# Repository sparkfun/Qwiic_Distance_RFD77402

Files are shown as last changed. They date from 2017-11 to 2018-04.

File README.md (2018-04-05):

Qwiic Distance Sensor - RFD77402
========================================

SparkFun Distance Sensor - RFD77402

[*Distance Sensor-RFD77402 (SEN-14539)*](https://www.sparkfun.com/products/14539)

The Qwiic Distance Sensor uses the RFD77402 sensor utilizing VCSEL or vertical-cavity surface-emitting laser and a 3 pixel camera to measure the amount of time to a target. This gives you amazing millimeter prescision with low-cost and low power.

Documentation
--------------
* **[Library](https://github.com/sparkfun/SparkFun_RFD77402_Arduino_Library)** - Arduino library for the RFD77402 Breakout Board.
* **[Hookup Guide](https://learn.sparkfun.com/tutorials/qwiic-distance-sensor-rfd77402-hookup-guide)** - Basic hookup guide for the RFD77402 Breakout Board.
* **[Qwiic System](http://www.sparkfun.com/qwiic)** - The Qwiic system enables fast and solderless connection between popular platforms and various sensors and actuators.

Product Versions
----------------
* [SEN-14539](https://www.sparkfun.com/products/14539)
* [SPX-14343](https://www.sparkfun.com/products/14343)

License Information
-------------------

This product is _**open source**_!

Please review the LICENSE.md file for license information.

If you have any questions or concerns on licensing, please contact techsupport@sparkfun.com.

Distributed as-is; no warranty is given.

- Your friends at SparkFun.

_<COLLABORATION CREDIT>_

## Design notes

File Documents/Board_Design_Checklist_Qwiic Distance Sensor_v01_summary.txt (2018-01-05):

1) Are the part libraries consistent with eagle github repo? [YES]
comment: Kicad, but yes

2) Do all VCC connections use the VCC symbol (oriented upward)? [YES]
comment: 3.3v

3) Is the bottom left corner board dimensions at 0,0? [YES]
comment: frame at 0,0

4) Is the board dimension outline correct thickness? (0.008 inch) [NO]
comment: .0059 (leaving as is, kicad)

5) If it is a 3-way jumper, is there a label on each side of the jumper? [NO]
comment: i2c pu

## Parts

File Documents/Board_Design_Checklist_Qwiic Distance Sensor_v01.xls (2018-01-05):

SECTION | CHECK | STATUS | DEPENDANCY | CORRECT ANSWER | USER | USER-ANSWER | COMMENT | WIKI_LINK
Macro | is_revision | 1
Macro | has_pth | 0
Macro | has_i2c | 1
Macro | has_SPI | 0
Macro | has_1x6_ftdi_header | 0
Macro | has_jumpers | 1
Macro | has_leds | 0
Macro | has_vreg | 0
Macro | has_QFN | 0
Macro | has_SS | 0
Macro | has_multi_sheet | 0
Macro | is_kit | 0
Macro | has_serial | 0
Macro | is_4layer | 0
Macro | has_milling | 0
Macro | has_switchorbutton | 0
General | Are the part libraries consistent with eagle github repo? |  |  | YES | andrew.england | YES | Kicad, but yes
Schematic | Is the proper frame with CC attribution used? |  |  | YES | andrew.england | YES
Schematic | Are all schematic objects inside the frame? |  |  | YES | andrew.england | YES
Schematic | Is there a SparkFun Logo? |  |  | YES | andrew.england | YES
Schematic | Is there an OSHW logo? |  |  | YES | andrew.england | YES
Schematic | Is proper attribution given to the original designer? |  |  | YES | andrew.england | YES
Schematic | Is "Revised by: " and the reviser's name present? |  | 2 | YES | andrew.england | YES
Schematic | Are NET labels the correct FLAG type? |  |  | YES | andrew.england | YES
Schematic | Have all nets been drawn straight out from pin connections at least one grid space? |  |  | YES | andrew.england | YES
Schematic | Are all net lines 0.006 inch? |  |  | YES | andrew.england | YES
Schematic | Are there any 4-way junctions? |  |  | NO | andrew.england | NO
Schematic | Are junction dots used for all 3-wire connections? |  |  | YES | andrew.england | YES
Schematic | Are the fiducials in the lower right corner? |  |  | YES | andrew.england | YES
Schematic | Are the standoffs in the lower right corner? |  |  | YES | andrew.england | YES
Schematic | Are dashed grey lines ('info' eagle layer 97) used to clearly separate different areas? |  |  | YES | andrew.england | YES
Schematic | Is the version number correct? |  |  | YES | andrew.england | YES
Schematic | Is the version number included on all sheets? |  | 12 | YES | andrew.england | *n/a*
Schematic | Do all GND connections use the GND symbol (oriented downward)? |  |  | YES | andrew.england | YES
Schematic | Do all VCC connections use the VCC symbol (oriented upward)? |  |  | YES | andrew.england | YES | 3.3v
Schematic | Is the VCC range clearly labeled? |  |  | YES | andrew.england | YES
Schematic | Are any jumpers labeled clearly by their function and possible settings? |  | 7 | YES | andrew.england | YES
Schematic | Are any appropriate warnings (voltage conversion, sensitive I/O) labeled? |  |  | YES | andrew.england | n/a
Schematic | Are any notes of two versions of the board in the schematic (3.3V regulator vs 5V regulator)? |  |  | YES | andrew.england | NO
Schematic | Do any part names have '/.~' in them? (Multiple sheets) |  | 12 | NO | andrew.england | *n/a*
Schematic | Have you verified that the BOM in Sparkle is accurate (also checking for PROD_ID, NAME, VALUE, PREFIX)? |  |  | YES | andrew.england | YES
Schematic | Do any parts have unnecessary values (Eagle has autoset the package as the value)? |  |  | NO | andrew.england | NO
Schematic | Regarding the voltage regulator, is the input on the LEFT, and the output on the RIGHT? |  | 9 | YES | andrew.england | *n/a*
Schematic | Is the I2C address in the schematic? |  | 4 | YES | andrew.england | YES
Schematic | Is it the standard I2C pin order used (GND/VCC/SDA/CLK)? |  | 4 | YES | andrew.england | YES |  | http://wiki.internal.sparkfun.com/index.php?title=Eagle_Rules#Pin_Out.2FConnection_Orientation
Schematic | Is the I2C pull-up resistor isolation jumper present? |  | 4 | YES | andrew.england | YES |  | http://wiki.internal.sparkfun.com/index.php?title=Eagle_Rules#Component_Placement
Schematic | Is the SPI pull-up resistor for Chip Select present? |  | 5 | YES | andrew.england | *n/a* |  | http://wiki.internal.sparkfun.com/index.php?title=Eagle_Rules#Component_Placement
Schematic | Is the MISO tri-state buffer included? |  | 5 | YES | andrew.england | *n/a* |  | http://wiki.internal.sparkfun.com/index.php?title=Eagle_Rules#Component_Placement
Board | Are the inner layers on the correct eagle layers? (2 and 15) |  | 15 | YES | andrew.england | *n/a* |  | http://wiki.internal.sparkfun.com/index.php?title=Eagle_Rules#Board_Creation.2C_Outline
Board | Does your 4 layer board include '1' '2' '3' '4' in the copper of each layer? |  | 15 | YES | andrew.england | *n/a* |  | http://wiki.internal.sparkfun.com/index.php?title=Eagle_Rules#Board_Creation.2C_Outline
Board | Is the bottom left corner board dimensions at 0,0? |  |  | YES | andrew.england | YES | frame at 0,0 | http://wiki.internal.sparkfun.com/index.php?title=Eagle_Rules#Board_Creation.2C_Outline
Board | Is the board dimension outline correct thickness? (0.008 inch) |  |  | YES | andrew.england | NO | .0059 (leaving as is, kicad) | http://wiki.internal.sparkfun.com/index.php?title=Eagle_Rules#Board_Creation.2C_Outline
Board | If this requires very precise dimensions (e.g. USB stick), did you consider GP's tolerances? (dimension=5mils, Vscore=10mils) |  |  |  | andrew.england | YES |  | http://wiki.internal.sparkfun.com/index.php?title=Eagle_Rules#Fab_house_Tolerances
Board | Are 0.1 inch headers lined up on 0.1 inch grid? |  |  | YES | andrew.england | YES |  | http://wiki.internal.sparkfun.com/index.php?title=Eagle_Rules#Board_Creation.2C_Outline
Board | Are opposing 0.1 inch headers spaced to fit into a breadboard? |  |  | YES | andrew.england | n/a |  | http://wiki.internal.sparkfun.com/index.php?title=Eagle_Rules#Board_Creation.2C_Outline
Board | Do all testpoints have a separation of at least 0.1 inch (preferably placed on a 0.05 inch grid)? |  |  | YES | andrew.england | YES |  | http://wiki.internal.sparkfun.com/index.php?title=Eagle_Rules#Board_Creation.2C_Outline
Board | Does the board have standoffs? |  |  | YES | andrew.england | YES |  | http://wiki.internal.sparkfun.com/index.php?title=Eagle_Rules#Board_Creation.2C_Outline
Board | Can standoffs/screws be used clear of other parts? |  |  | YES | andrew.england | YES |  | http://wiki.internal.sparkfun.com/index.php?title=Eagle_Rules#Board_Creation.2C_Outline
Board | Is the FTDI connector accessible (do neighboring parts allow enough space to clear each side)? |  | 6 | YES | andrew.england | *n/a* |  | http://wiki.internal.sparkfun.com/index.php?title=Eagle_Rules#Pin_Out.2FConnection_Orientation
Board | Is the FTDI connector oriented so the FTDI breakout can be slid on properly (IC side up, header side down)? |  | 6 | YES | andrew.england | *n/a* |  | http://wiki.internal.sparkfun.com/index.php?title=Eagle_Rules#Pin_Out.2FConnection_Orientation
Board | Are vias tented correctly? |  |  | YES | andrew.england | YES |  | http://wiki.internal.sparkfun.com/index.php?title=Eagle_Rules
Board | If possible, are all overhanging parts on the same edge of the board (this helps with panelization)? |  |  | YES | andrew.england | YES |  | http://wiki.internal.sparkfun.com/index.php?title=Eagle_Rules#Pin_Out.2FConnection_Orientation
Board | Does this board adhere to the standard manufacturing process? (Kitting time, glue curing, humidor time, etc.) |  |  | YES | andrew.england | YES
Board | Are any vias intended to be used as PTH headers (they shouldn't be)? |  |  | NO | andrew.england | NO |  | http://wiki.internal.sparkfun.com/index.php?title=Eagle_Rules
Board | Is the LED color standard followed? (red for power, blue for STAT, green for TX, yellow for RX) |  | 8 | YES | andrew.england | *n/a* |  | http://wiki.internal.sparkfun.com/index.php?title=Eagle_Rules#Component_Placement
Board | Are all PTH parts selective solder compatible? (same side, plenty of clearance around pins) |  | 11 | YES | andrew.england | *n/a* |  | http://wiki.internal.sparkfun.com/index.php?title=Eagle_Rules#Pin_Out.2FConnection_Orientation
Board | As best as possible, do all SMD pads have only 1 trace entering the pad? |  |  | YES | andrew.england | YES |  | http://wiki.internal.sparkfun.com/index.php?title=Eagle_Rules#PCB_Layout
Board | Are there any natural bridges on SMT components? |  |  | NO | andrew.england | NO |  | http://wiki.internal.sparkfun.com/index.php?title=Eagle_Rules#PCB_Layout
Board | Do V-Scored edges have a 50 mil border free of pads and parts (to prevent cracking on separation)? |  |  | YES | andrew.england | YES
Board | Is the direction of TX/RX serial connections correct? |  | 14 | YES | andrew.england | *n/a*
Board | Are the TX/RX pins of the FTDI properly connected? |  | 6 | YES | andrew.england | *n/a*
Board | Is trace routing up to spec? (to/from center-points, straight lines, 45 angles, 'T' intersections, no right angles or acid traps) |  |  | YES | andrew.england | YES |  | http://wiki.internal.sparkfun.com/index.php?title=Eagle_Rules#PCB_Layout
Board | For thermal considerations, are traces routed away from the component, with symmetrical routing? |  | 10 | YES | andrew.england | *n/a*
Board | Do all footprints pass 1:1 check? (Applies mostly to new components) |  |  | YES | andrew.england | YES
Board | Are all QFN components with 6 or more leads 75 percent pasted on lead pads? (May be contended depending on performance) |  | 10 | YES | andrew.england | *n/a* |  | http://wiki.internal.sparkfun.com/index.php?title=Eagle_Rules#Footprints.2FPackages
Board | Are center pad cream apertures properly reduced? (50-75% paste is good) |  | 10 | YES | andrew.england | *n/a* |  | http://wiki.internal.sparkfun.com/index.php?title=Eagle_Rules#Footprints.2FPackages
Board | Is there solder mask between pads on of 11 mil separation and greater? |  |  | YES | andrew.england | YES |  | http://wiki.internal.sparkfun.com/index.php?title=Eagle_Rules#Fab_house_Tolerances
Board | Is there a correct version number in the copper (aligned properly with the edge of the PCB)? |  |  | YES | andrew.england | YES
Board | Are there fiducials on both the TOP and BOTTOM of the board? |  |  | YES | andrew.england | YES
Board | Does it pass DRC with top/bottom keepout layers on? |  |  | YES | andrew.england | YES
Board | If there are any DRC errors, have they all been approved? |  |  | YES | andrew.england | YES
Board | Are there airwires after ratsnest? |  |  | NO | andrew.england | NO
Board | Are all KIT PTH parts on the correct side with correct masking (e.g. the TSTOP or BSTOP expose the correct side) |  | 13 | YES | andrew.england | *n/a*
Documentation | Is there a note for a 4-layer board (on tDOCU)? |  | 15 | YES | andrew.england | *n/a*
Documentation | Do all packages have NAME and VALUE? |  |  | YES | andrew.england | YES
Documentation | Is there a note for a board thickness other than 0.63 inch? |  |  |  | andrew.england | NO
Documentation | Are measurements included for outer dimension and standoffs (Eagle layer 47)? |  |  | YES | andrew.england | YES
Documentation | Are the board dimensions on 0.05 inch or 0.01 inch grid? |  |  | YES | andrew.england | YES
Documentation | Are routed-out areas labeled 'ROUTE OUT' (on dimension)? |  | 16 | YES | andrew.england | *n/a*
Documentation | Is the CC/Design By included in tDocu? |  |  | YES | andrew.england | YES
Documentation | Is the designer name included in tDocu? |  |  | YES | andrew.england | YES
Documentation | Is 'Revised by:' and 'Revisor Name' included in tDocu? |  | 2 | YES | andrew.england | YES
Silkscreen/Labeling | Is the name of the board on the board? |  |  | YES | andrew.england | YES |  | http://wiki.internal.sparkfun.com/index.php?title=Eagle_Rules#PCB_Silk
Silkscreen/Labeling | Do all footprints have 0.008 inch silk footprint? |  |  | YES | andrew.england | YES
Silkscreen/Labeling | Are all LEDs labeled with their purpose? |  | 8 | YES | andrew.england | *n/a*
Silkscreen/Labeling | Are all PTHs (aka connectors) clearly labeled with their purpose on both sides of the board? |  |  | YES | andrew.england | YES
Silkscreen/Labeling | Are battery terminals labeled +/- correctly? |  |  | YES | andrew.england | n/a
Silkscreen/Labeling | Are all jumpers labeled? |  | 7 | YES | andrew.england | YES
Silkscreen/Labeling | If it is a 3-way jumper, is there a label on each side of the jumper? |  | 7 | YES | andrew.england | NO | i2c pu
Silkscreen/Labeling | Are all switches/buttons labeled properly? |  | 17 | YES | andrew.england | *n/a*
Silkscreen/Labeling | Are active low pins labeled clearly? |  |  | YES | andrew.england | YES
Silkscreen/Labeling | Are all labels lined up properly? |  |  | YES | andrew.england | YES
Silkscreen/Labeling | Is all text at least 0.032 inch, 15 percent radio, and vector? |  |  | YES | andrew.england | YES
Silkscreen/Labeling | Does the FTDI connector have BLK/GRN labeled correctly? |  | 6 | YES | andrew.england | *n/a*
Silkscreen/Labeling | Do all components have polarity or pin 1 labeled? |  |  | YES | andrew.england | YES
Silkscreen/Labeling | Is the polarity label outside of the package for visibility after part population? |  |  | YES | andrew.england | YES
Silkscreen/Labeling | Are there check labels for different versions of the board (3.3V vs 5V)? |  |  | YES | andrew.england | NO
Silkscreen/Labeling | Is the SparkFun Logo on the board? |  |  | YES | andrew.england | YES
Silkscreen/Labeling | Is the OSHW logo on the board? |  |  | YES | andrew.england | YES
Silkscreen/Labeling | Is any silkscreen overlaid on vias? |  |  | NO | andrew.england | NO
Silkscreen/Labeling | Is there a URL for any kits or unique boards? |  |  |  | andrew.england | NO
Special | Are dimension lines properly spaced for V-scoring (lines on a 0.020” center-to-center spacing)? |  |  |  | andrew.england | NO
Special | On white solder mask pcbs, is there any solder mask between leads on large SMT components? |  |  |  | andrew.england | NO
Special | Are axes labeled correctly? |  |  |  | andrew.england | n/a
Special | Are there warning labels for high voltage areas? |  |  |  | andrew.england | n/a
END | Thanks for flying with us. Have a great day!! |  |  |  | andrew.england | n/a

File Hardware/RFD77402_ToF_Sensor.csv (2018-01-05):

Reference | Quantity | Value | Footprint | Datasheet | Field4
C1 | 1 | 0.1UF-0603-25V-_+80_-20%_ | Capacitors:0603 |  | CAP-00810
C2 | 1 | 4.7UF0603 | Capacitors:0603 |  | CAP-08280
F1 F2 F3 F4 | 4 | Fiducial | Aesthetics:FIDUCIAL-MICRO
J1 J2 | 2 | QWIIC_CONNECTORJS-1MM | Connectors:1X04_1MM_RA |  | CONN-13694
J3 | 1 | CONN_01 | Connectors:1X01 |  | XXX-00000
J4 | 1 | I2C_STANDARD | Connectors:1X04 |  | XXX-00000
JP1 | 1 | JUMPER-SMT_3_2-NC_PASTE_SILK | SparkFun-Jumpers:SMT-JUMPER_3_2-NC_PASTE_SILK
LOGO1 | 1 | SPARKFUN-AESTHETICS_OSHW-LOGOS | SparkFun-Aesthetics:OSHW-LOGO-MINI
LOGO2 LOGO3 | 2 | SFE_LOGO_NAME_FLAME.1_INCH | Aesthetics:SFE_LOGO_NAME_FLAME_.1 |  | XXX-00000
MK1 MK2 | 2 | Mounting_Hole | SparkFun-Hardware:STAND-OFF
R1 R2 | 2 | 4.7KOHM-0603-1_10W-1% | Resistors:0603 |  | RES-07857
U1 | 1 | RFD77402 | Silicon-Custom:RFD77402 |  | IC-13870
U4 | 1 | CC_LICENSE | SparkFun-Aesthetics:CREATIVE_COMMONS

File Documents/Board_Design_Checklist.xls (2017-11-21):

SECTION | CHECK | STATUS | DEPENDANCY | CORRECT ANSWER | USER | USER-ANSWER | COMMENT | WIKI_LINK
Macro | is_revision | 0
Macro | has_pth | 0
Macro | has_i2c | 0
Macro | has_SPI | 0
Macro | has_1x6_ftdi_header | 0
Macro | has_jumpers | 0
Macro | has_leds | 0
Macro | has_vreg | 0
Macro | has_QFN | 0
Macro | has_SS | 0
Macro | has_multi_sheet | 0
Macro | is_kit | 0
Macro | has_serial | 0
Macro | is_4layer | 0
Macro | has_milling | 0
Macro | has_switchorbutton | 0
General | Are the part libraries consistent with eagle github repo? |  |  | YES
Schematic | Is the proper frame with CC attribution used? |  |  | YES
Schematic | Are all schematic objects inside the frame? |  |  | YES
Schematic | Is there a SparkFun Logo? |  |  | YES
Schematic | Is there an OSHW logo? |  |  | YES
Schematic | Is proper attribution given to the original designer? |  |  | YES
Schematic | Is "Revised by: " and the reviser's name present? |  | 2 | YES
Schematic | Are NET labels the correct FLAG type? |  |  | YES
Schematic | Have all nets been drawn straight out from pin connections at least one grid space? |  |  | YES
Schematic | Are all net lines 0.006 inch? |  |  | YES
Schematic | Are there any 4-way junctions? |  |  | NO
Schematic | Are junction dots used for all 3-wire connections? |  |  | YES
Schematic | Are the fiducials in the lower right corner? |  |  | YES
Schematic | Are the standoffs in the lower right corner? |  |  | YES
Schematic | Are dashed grey lines ('info' eagle layer 97) used to clearly separate different areas? |  |  | YES
Schematic | Is the version number correct? |  |  | YES
Schematic | Is the version number included on all sheets? |  | 12 | YES
Schematic | Do all GND connections use the GND symbol (oriented downward)? |  |  | YES
Schematic | Do all VCC connections use the VCC symbol (oriented upward)? |  |  | YES
Schematic | Is the VCC range clearly labeled? |  |  | YES
Schematic | Are any jumpers labeled clearly by their function and possible settings? |  | 7 | YES
Schematic | Are any appropriate warnings (voltage conversion, sensitive I/O) labeled? |  |  | YES
Schematic | Are any notes of two versions of the board in the schematic (3.3V regulator vs 5V regulator)? |  |  | YES
Schematic | Do any part names have '/.~' in them? (Multiple sheets) |  | 12 | NO
Schematic | Have you verified that the BOM in Sparkle is accurate (also checking for PROD_ID, NAME, VALUE, PREFIX)? |  |  | YES
Schematic | Do any parts have unnecessary values (Eagle has autoset the package as the value)? |  |  | NO
Schematic | Regarding the voltage regulator, is the input on the LEFT, and the output on the RIGHT? |  | 9 | YES
Schematic | Is the I2C address in the schematic? |  | 4 | YES
Schematic | Is it the standard I2C pin order used (GND/VCC/SDA/CLK)? |  | 4 | YES |  |  |  | http://wiki.internal.sparkfun.com/index.php?title=Eagle_Rules#Pin_Out.2FConnection_Orientation
Schematic | Is the I2C pull-up resistor isolation jumper present? |  | 4 | YES |  |  |  | http://wiki.internal.sparkfun.com/index.php?title=Eagle_Rules#Component_Placement
Schematic | Is the SPI pull-up resistor for Chip Select present? |  | 5 | YES |  |  |  | http://wiki.internal.sparkfun.com/index.php?title=Eagle_Rules#Component_Placement
Schematic | Is the MISO tri-state buffer included? |  | 5 | YES |  |  |  | http://wiki.internal.sparkfun.com/index.php?title=Eagle_Rules#Component_Placement
Board | Are the inner layers on the correct eagle layers? (2 and 15) |  | 15 | YES |  |  |  | http://wiki.internal.sparkfun.com/index.php?title=Eagle_Rules#Board_Creation.2C_Outline
Board | Does your 4 layer board include '1' '2' '3' '4' in the copper of each layer? |  | 15 | YES |  |  |  | http://wiki.internal.sparkfun.com/index.php?title=Eagle_Rules#Board_Creation.2C_Outline
Board | Is the bottom left corner board dimensions at 0,0? |  |  | YES |  |  |  | http://wiki.internal.sparkfun.com/index.php?title=Eagle_Rules#Board_Creation.2C_Outline
Board | Is the board dimension outline correct thickness? (0.008 inch) |  |  | YES |  |  |  | http://wiki.internal.sparkfun.com/index.php?title=Eagle_Rules#Board_Creation.2C_Outline
Board | If this requires very precise dimensions (e.g. USB stick), did you consider GP's tolerances? (dimension=5mils, Vscore=10mils) |  |  |  |  |  |  | http://wiki.internal.sparkfun.com/index.php?title=Eagle_Rules#Fab_house_Tolerances
Board | Are 0.1 inch headers lined up on 0.1 inch grid? |  |  | YES |  |  |  | http://wiki.internal.sparkfun.com/index.php?title=Eagle_Rules#Board_Creation.2C_Outline
Board | Are opposing 0.1 inch headers spaced to fit into a breadboard? |  |  | YES |  |  |  | http://wiki.internal.sparkfun.com/index.php?title=Eagle_Rules#Board_Creation.2C_Outline
Board | Do all testpoints have a separation of at least 0.1 inch (preferably placed on a 0.05 inch grid)? |  |  | YES |  |  |  | http://wiki.internal.sparkfun.com/index.php?title=Eagle_Rules#Board_Creation.2C_Outline
Board | Does the board have standoffs? |  |  | YES |  |  |  | http://wiki.internal.sparkfun.com/index.php?title=Eagle_Rules#Board_Creation.2C_Outline
Board | Can standoffs/screws be used clear of other parts? |  |  | YES |  |  |  | http://wiki.internal.sparkfun.com/index.php?title=Eagle_Rules#Board_Creation.2C_Outline
Board | Is the FTDI connector accessible (do neighboring parts allow enough space to clear each side)? |  | 6 | YES |  |  |  | http://wiki.internal.sparkfun.com/index.php?title=Eagle_Rules#Pin_Out.2FConnection_Orientation
Board | Is the FTDI connector oriented so the FTDI breakout can be slid on properly (IC side up, header side down)? |  | 6 | YES |  |  |  | http://wiki.internal.sparkfun.com/index.php?title=Eagle_Rules#Pin_Out.2FConnection_Orientation
Board | Are vias tented correctly? |  |  | YES |  |  |  | http://wiki.internal.sparkfun.com/index.php?title=Eagle_Rules
Board | If possible, are all overhanging parts on the same edge of the board (this helps with panelization)? |  |  | YES |  |  |  | http://wiki.internal.sparkfun.com/index.php?title=Eagle_Rules#Pin_Out.2FConnection_Orientation
Board | Does this board adhere to the standard manufacturing process? (Kitting time, glue curing, humidor time, etc.) |  |  | YES
Board | Are any vias intended to be used as PTH headers (they shouldn't be)? |  |  | NO |  |  |  | http://wiki.internal.sparkfun.com/index.php?title=Eagle_Rules
Board | Is the LED color standard followed? (red for power, blue for STAT, green for TX, yellow for RX) |  | 8 | YES |  |  |  | http://wiki.internal.sparkfun.com/index.php?title=Eagle_Rules#Component_Placement
Board | Are all PTH parts selective solder compatible? (same side, plenty of clearance around pins) |  | 11 | YES |  |  |  | http://wiki.internal.sparkfun.com/index.php?title=Eagle_Rules#Pin_Out.2FConnection_Orientation
Board | As best as possible, do all SMD pads have only 1 trace entering the pad? |  |  | YES |  |  |  | http://wiki.internal.sparkfun.com/index.php?title=Eagle_Rules#PCB_Layout
Board | Are there any natural bridges on SMT components? |  |  | NO |  |  |  | http://wiki.internal.sparkfun.com/index.php?title=Eagle_Rules#PCB_Layout
Board | Do V-Scored edges have a 50 mil border free of pads and parts (to prevent cracking on separation)? |  |  | YES
Board | Is the direction of TX/RX serial connections correct? |  | 14 | YES
Board | Are the TX/RX pins of the FTDI properly connected? |  | 6 | YES
Board | Is trace routing up to spec? (to/from center-points, straight lines, 45 angles, 'T' intersections, no right angles or acid traps) |  |  | YES |  |  |  | http://wiki.internal.sparkfun.com/index.php?title=Eagle_Rules#PCB_Layout
Board | For thermal considerations, are traces routed away from the component, with symmetrical routing? |  | 10 | YES
Board | Do all footprints pass 1:1 check? (Applies mostly to new components) |  |  | YES
Board | Are all QFN components with 6 or more leads 75 percent pasted on lead pads? (May be contended depending on performance) |  | 10 | YES |  |  |  | http://wiki.internal.sparkfun.com/index.php?title=Eagle_Rules#Footprints.2FPackages
Board | Are center pad cream apertures properly reduced? (50-75% paste is good) |  | 10 | YES |  |  |  | http://wiki.internal.sparkfun.com/index.php?title=Eagle_Rules#Footprints.2FPackages
Board | Is there solder mask between pads on of 11 mil separation and greater? |  |  | YES |  |  |  | http://wiki.internal.sparkfun.com/index.php?title=Eagle_Rules#Fab_house_Tolerances
Board | Is there a correct version number in the copper (aligned properly with the edge of the PCB)? |  |  | YES
Board | Are there fiducials on both the TOP and BOTTOM of the board? |  |  | YES
Board | Does it pass DRC with top/bottom keepout layers on? |  |  | YES
Board | If there are any DRC errors, have they all been approved? |  |  | YES
Board | Are there airwires after ratsnest? |  |  | NO
Board | Are all KIT PTH parts on the correct side with correct masking (e.g. the TSTOP or BSTOP expose the correct side) |  | 13 | YES
Documentation | Is there a note for a 4-layer board (on tDOCU)? |  | 15 | YES
Documentation | Do all packages have NAME and VALUE? |  |  | YES
Documentation | Is there a note for a board thickness other than 0.63 inch?
Documentation | Are measurements included for outer dimension and standoffs (Eagle layer 47)? |  |  | YES
Documentation | Are the board dimensions on 0.05 inch or 0.01 inch grid? |  |  | YES
Documentation | Are routed-out areas labeled 'ROUTE OUT' (on dimension)? |  | 16 | YES
Documentation | Is the CC/Design By included in tDocu? |  |  | YES
Documentation | Is the designer name included in tDocu? |  |  | YES
Documentation | Is 'Revised by:' and 'Revisor Name' included in tDocu? |  | 2 | YES
Silkscreen/Labeling | Is the name of the board on the board? |  |  | YES |  |  |  | http://wiki.internal.sparkfun.com/index.php?title=Eagle_Rules#PCB_Silk
Silkscreen/Labeling | Do all footprints have 0.008 inch silk footprint? |  |  | YES
Silkscreen/Labeling | Are all LEDs labeled with their purpose? |  | 8 | YES
Silkscreen/Labeling | Are all PTHs (aka connectors) clearly labeled with their purpose on both sides of the board? |  |  | YES
Silkscreen/Labeling | Are battery terminals labeled +/- correctly? |  |  | YES
Silkscreen/Labeling | Are all jumpers labeled? |  | 7 | YES
Silkscreen/Labeling | If it is a 3-way jumper, is there a label on each side of the jumper? |  | 7 | YES
Silkscreen/Labeling | Are all switches/buttons labeled properly? |  | 17 | YES
Silkscreen/Labeling | Are active low pins labeled clearly? |  |  | YES
Silkscreen/Labeling | Are all labels lined up properly? |  |  | YES
Silkscreen/Labeling | Is all text at least 0.032 inch, 15 percent radio, and vector? |  |  | YES
Silkscreen/Labeling | Does the FTDI connector have BLK/GRN labeled correctly? |  | 6 | YES
Silkscreen/Labeling | Do all components have polarity or pin 1 labeled? |  |  | YES
Silkscreen/Labeling | Is the polarity label outside of the package for visibility after part population? |  |  | YES
Silkscreen/Labeling | Are there check labels for different versions of the board (3.3V vs 5V)? |  |  | YES
Silkscreen/Labeling | Is the SparkFun Logo on the board? |  |  | YES
Silkscreen/Labeling | Is the OSHW logo on the board? |  |  | YES
Silkscreen/Labeling | Is any silkscreen overlaid on vias? |  |  | NO
Silkscreen/Labeling | Is there a URL for any kits or unique boards?
Special | Are dimension lines properly spaced for V-scoring (lines on a 0.020” center-to-center spacing)?
Special | On white solder mask pcbs, is there any solder mask between leads on large SMT components?
Special | Are axes labeled correctly?
Special | Are there warning labels for high voltage areas?
END | Thanks for flying with us. Have a great day!!

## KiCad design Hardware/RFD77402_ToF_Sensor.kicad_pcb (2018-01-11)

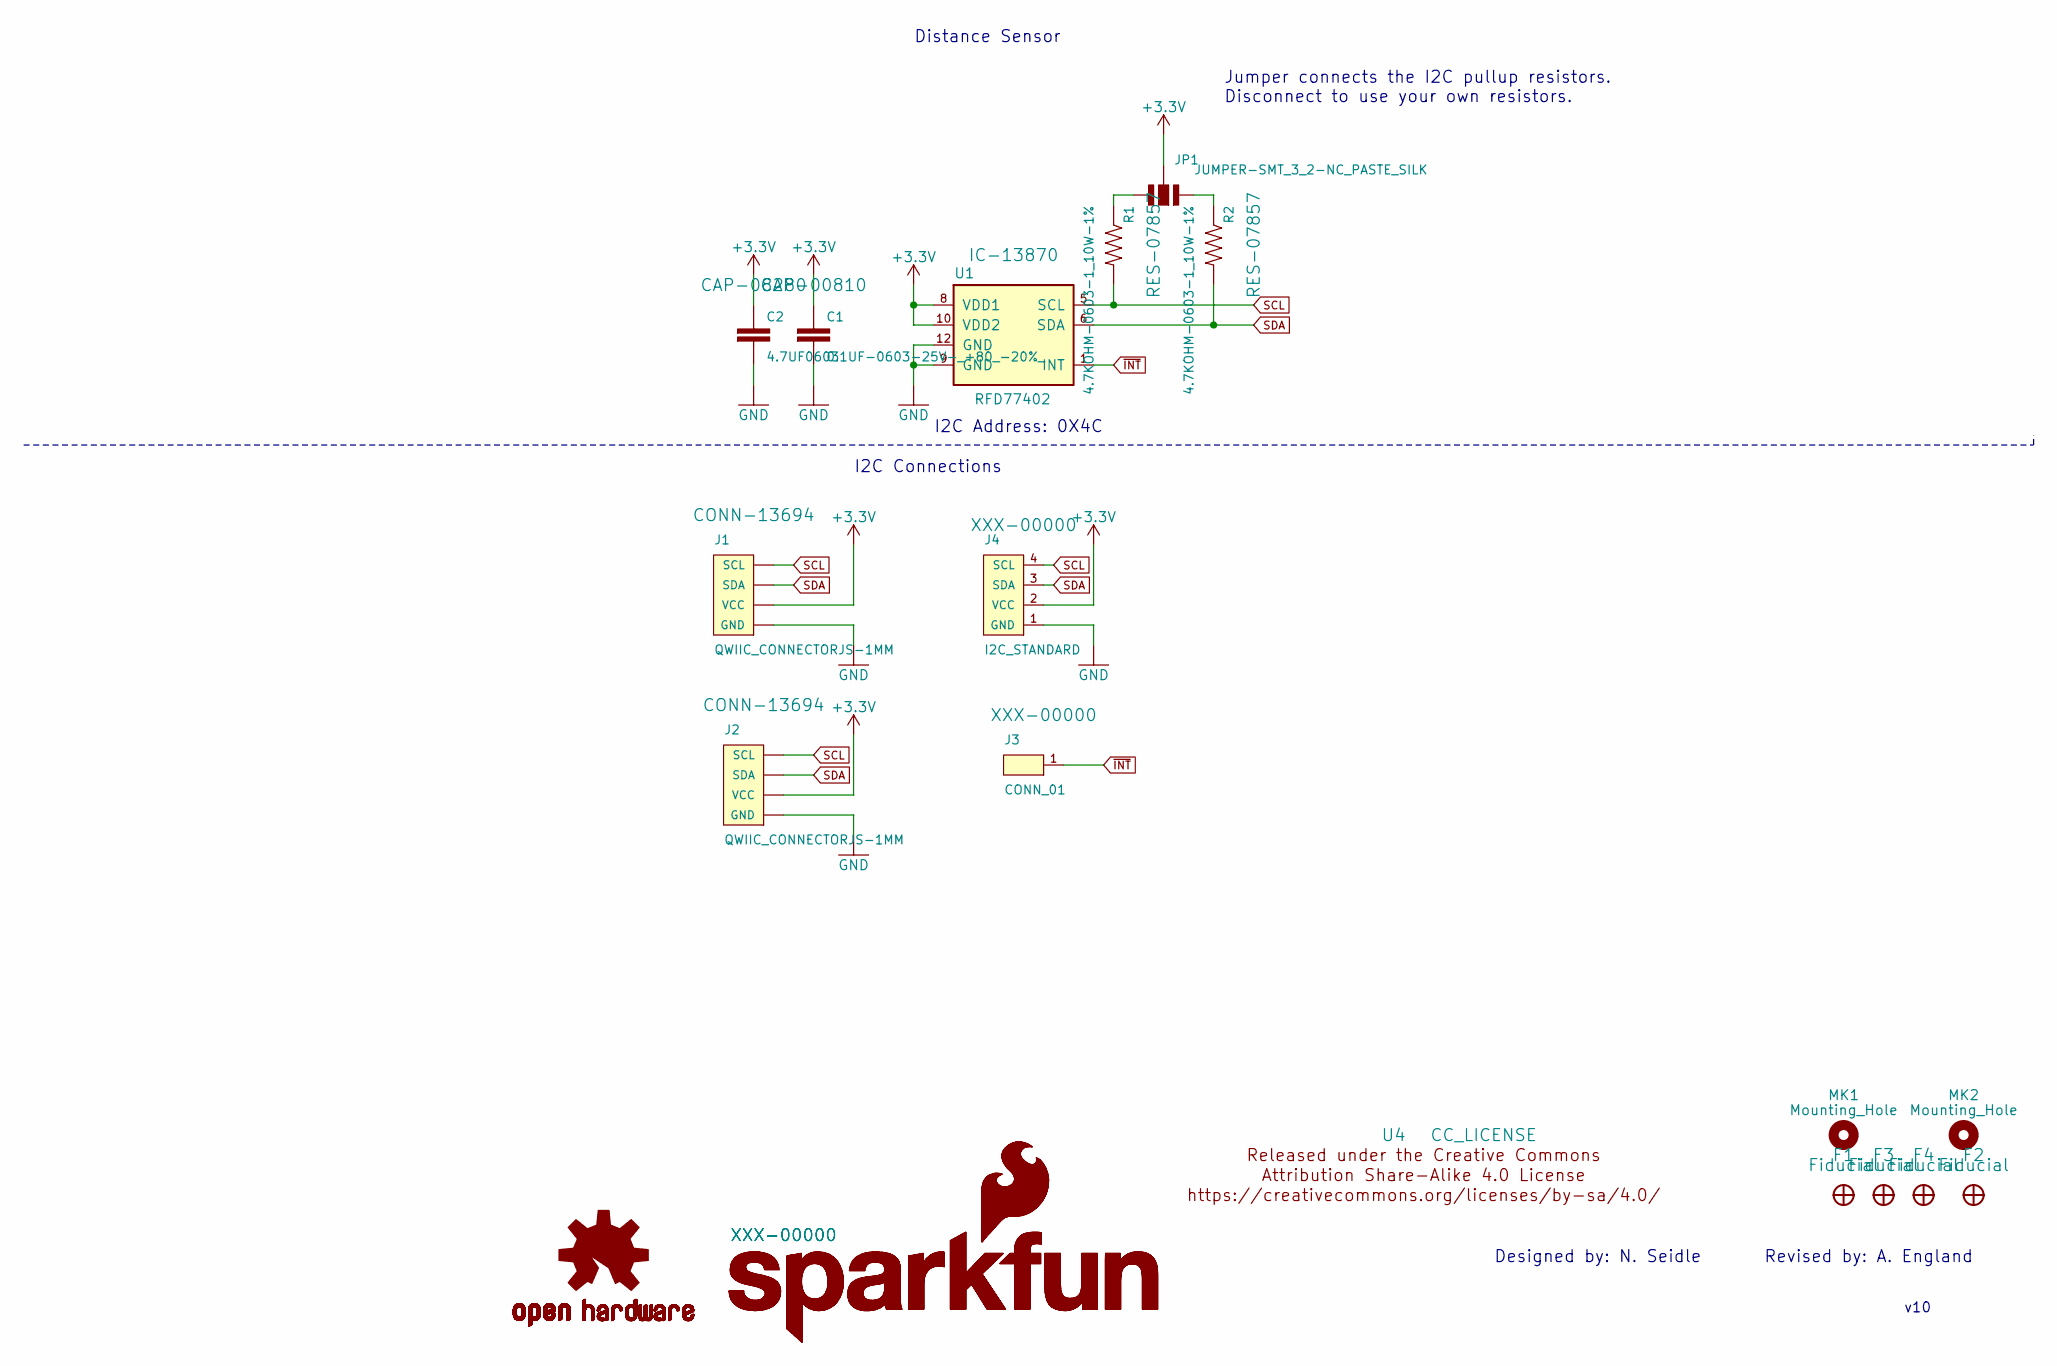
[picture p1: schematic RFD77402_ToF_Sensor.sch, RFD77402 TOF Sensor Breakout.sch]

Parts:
C1: 0.1UF-0603-25V-_+80_-20%_; 0603
C2: 4.7UF0603; 0603
F1, F2, F3, F4: Fiducial; FIDUCIAL-MICRO-NO_PASTE
J1, J2: QWIIC_CONNECTORJS-1MM; 1X04_1MM_RA
J3: CONN_01; 1X01
J4: I2C_STANDARD; 1X04
JP1: JUMPER-SMT_3_2-NC_PASTE_SILK; SMT-JUMPER_3_2-NC_PASTE_SILK
LOGO1: SPARKFUN-AESTHETICS_OSHW-LOGOS; OSHW-LOGO-MINI
LOGO2, LOGO3: SFE_LOGO_NAME_FLAME.1_INCH; SFE_LOGO_NAME_FLAME_.1
MK1, MK2: Mounting_Hole; STAND-OFF
R1, R2: 4.7KOHM-0603-1_10W-1%; 0603
U1: RFD77402
U4: CC_LICENSE; CREATIVE_COMMONS

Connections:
+3V3: C1.1, C2.1, J1.2 (VCC), J2.2 (VCC), J4.2 (VCC), JP1.2, U1.8 (VDD1), U1.10 (VDD2)
GND: C1.2, C2.2, J1.1 (GND), J2.1 (GND), J4.1 (GND), U1.9 (GND), U1.12 (GND)
unnamed: JP1.1, R2.1
unnamed: JP1.3, R1.1
SCL: J1.4 (SCL), J2.4 (SCL), J4.4 (SCL), R1.2, U1.5 (SCL)
SDA: J1.3 (SDA), J2.3 (SDA), J4.3 (SDA), R2.2, U1.6 (SDA)
~INT: J3.1, U1.1 (INT)

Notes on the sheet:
v10
Distance Sensor
I2C Connections
Jumper connects the I2C pullup resistors. Disconnect to use your own resistors.
I2C Address: 0X4C
Designed by: N. Seidle
Revised by: A. England

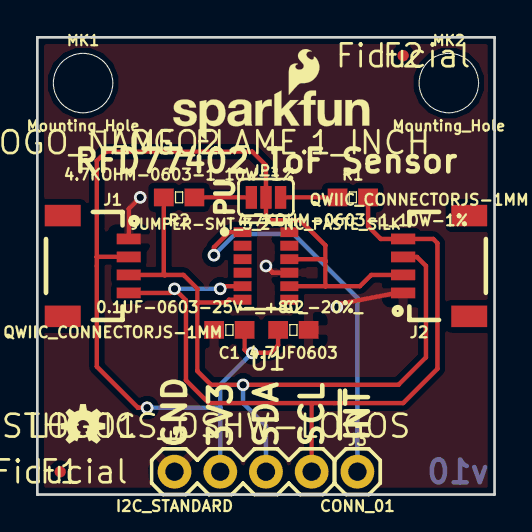
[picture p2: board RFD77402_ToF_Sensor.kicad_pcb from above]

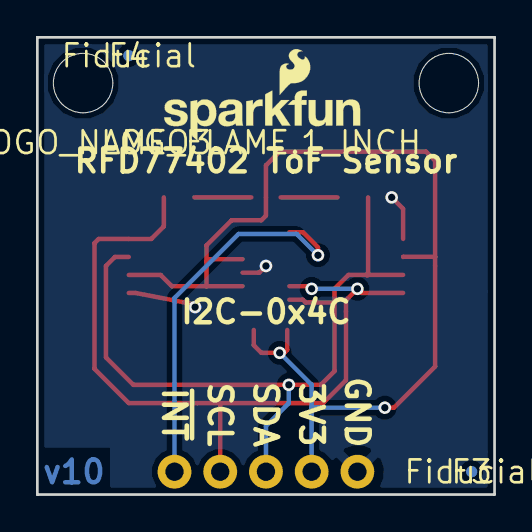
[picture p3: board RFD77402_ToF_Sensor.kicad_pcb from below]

Board: 2 copper layers, 25.4 x 25.4 mm, 20 parts (3 on the bottom side), 7 nets.

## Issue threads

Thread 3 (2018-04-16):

Attaching lens to RFD77402

nseidle, 2018-04-16:
How do you attach a lens to the RFD77402 as mentioned in section 6 of [the datasheet](https://cdn.sparkfun.com/assets/a/d/3/e/2/Simblee_RFD77402_Datasheet_Rev_1-8__1_.pdf)?

The Qwiic connectors/JSTs are higher than the sensor so you can either hot air off the JSTs and glue acrylic to the FR4 base with silicon. Or you could leave the JSTs on leaving a 2mm air gap between the face of the RFD77402 and the cover glass. It's not known how the air gap will affect overall read range.

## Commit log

2017-11-15 Changed board silk
    [RFD-Panel-B.Cu.gbl, RFD-Panel-B.Mask.gbs, RFD-Panel-B.SilkS.gbo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]
2017-11-17 Added fiducials
    [RFD77402_ToF_Sensor.kicad_pcb, RFD77402_ToF_Sensor.sch]
2017-11-21 Post design review changes
    [Board_Design_Checklist.xls, Board_Design_Checklist_Qwiic Distance Sensor_v01.xls, RFD77402_ToF_Sensor.kicad_pcb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]
2017-11-28 Post checklist changes
    [RFD77402_ToF_Sensor.kicad_pcb]
2018-01-11 fixed paste issue with fiducial
    [RFD77402_ToF_Sensor.kicad_pcb, RFD77402_ToF_Sensor.sch]

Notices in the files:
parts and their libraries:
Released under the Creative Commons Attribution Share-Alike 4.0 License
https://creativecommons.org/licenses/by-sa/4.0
